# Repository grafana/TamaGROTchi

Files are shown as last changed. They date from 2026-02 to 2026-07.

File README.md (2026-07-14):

# Tamagrotchi

A Tamagotchi for Grafana users, featuring **Grot** as your virtual pet.
Keep Grot alive, watch him evolve, and observe his vital signs flowing into Grafana Cloud as OTLP metrics, logs, and traces.

Built for Grafana Labs Hackathon and featuring at the GrafanaCon Science Fair



---

## Building & Flashing

```bash
# Install PlatformIO CLI if needed
pip install platformio

# Build
pio run

# Flash firmware
pio run --target upload

# Flash filesystem (config.json)
pio run --target uploadfs

# Serial monitor
pio device monitor
```

---

## Configuration

Copy `data/config.json.example` to `data/config.json` and fill in your credentials:

```json
{
  "wifi": {
    "ssid": "YOUR_SSID",
    "password": "YOUR_PASSWORD"
  },
  "grafana": {
    "otlp_base": "https://otlp-gateway-prod-<region>.grafana.net/otlp",
    "auth_b64":  "Basic <your_grafana_cloud_token>",
    "device_id": "tamagrotchi"
  },
  "game": {
    "demo_speed": false,
    "push_interval_s": 60,
    "buzzer": true,
    "flash_alerts": true
  },
  "display": {
    "bgr_order": false
  }
}
```

If your display colours seem odd, then set bgr_order to true

> **Auth note:** `auth_b64` must be `Basic <base64(instanceId:glc_token)>` — Grafana Cloud OTLP uses standard Basic auth where the username is your stack's OTLP instance ID and the password is the `glc_` token. Find the instance ID on the **OpenTelemetry → Configure** page of your Grafana Cloud stack, then encode the pair with:
>
> ```sh
> echo -n "<instanceId>:<glc_token>" | base64
> ```
>
> Passing the raw `glc_` token after "Basic" will result in `401 Unauthorized`.

Upload the filesystem image after editing: **PlatformIO → Upload Filesystem Image**.

---

## Hardware

The physical device is built around a Waveshare ESP32-S3-Touch-LCD-1.69

| Component | Detail |
|---|---|
| MCU | ESP32-S3, dual-core 240 MHz, 8 MB PSRAM |
| Display | 240×280 ST7789V2 IPS, SPI @ 40 MHz |
| IMU | QMI8658C (accel + gyro) via I2C |
| RTC | PCF85063A via I2C |
| Touch | CST816 capacitive (I2C) |
| Buttons | A / B / C (GPIO3, 17, 18 — active-LOW) |
| Buzzer | GPIO42 via LEDC |
| Battery | LiPo with ADC divider on GPIO1 |

A printable case is included in `hardware/` (STL + 3MF).

Instructions are available at [hardware/hardware-bom.md](hardware/hardware-bom.md)

---

## The App

### Grot's Life Cycle
- 6 life stages: **Egg → Baby → Child → Teen → Adult → Senior**
- Evolution triggered by age thresholds, with an "EVOLVING…" overlay and melody
- **Evolution quality** (Excellent / Good / Tired) determined by accumulated care mistakes — affects which sprite set is shown

### Vitals
- **Hunger**, **Happiness**, **Health** — all 0–100
- Stats decay each game tick; health slowly recovers when both hunger and happiness are above 50
- Alerts fire (buzzer + log) when either falls below threshold
- Sustained low hunger causes sickness; untreated sickness causes death

### Player Actions
| Button | Action |
|---|---|
| A | Previous Menu |
| B | Select |
| C | Next Menu |
| B (when Idle) | Cycle through animations |
| Gentle shake | Play / wake from sleep |
| Hard shake | Dizzy (-5 happiness, status effect) |

### Sleep / Wake
- Grot sleeps from 22:00 to 08:00 (RTC-based)
- Waking him early is a care mistake
- NTP time is synced to the hardware RTC on first WiFi connection

### Sprites
All frames use `LV_COLOR_FORMAT_RGB565A8` (RGB565 + alpha map), rendered at 3× scale via LVGL image-level transforms.

| Sprite sheet | Size | Frames | Used for |
|---|---|---|---|
| `egg-shake.png` | 38×38 | 3 | Egg idle + periodic shake animation |
| `grot.png` | 32×32 | 4 | Baby idle, tired adult idle |
| `grot-blink.png` | 32×32 | 2 | Sleeping |
| `grot-wave.png` | 32×32 | 6 | Happy (baby, child, good adult) |
| `grot-walk.png` | 32×32 | 8 | Child idle, excellent adult idle (+ left-facing variant) |
| `grot-jumping.png` | 32×32 | 8 | Happy (excited adult), dizzy (last 4 fr) |
| `grot-thinks.png` | 32×32 | 5 | Sad, sick, dead |

The egg sits still for ~3 s then shakes (three 50 ms frames) before returning to rest.

### Telemetry → Grafana Cloud
All telemetry is sent via **OTLP/HTTP JSON** to Grafana Cloud on a configurable interval (default 60 s).

**Metrics** (`/v1/metrics`):
- `grot.hunger`, `grot.happiness`, `grot.health` — vital signs
- `grot.age_seconds` — pet age
- `grot.care_mistakes` — evolution quality indicator
- `grot.battery_voltage` — LiPo charge level
- `grot.wifi_rssi` — signal strength
- `grot.accel_mag` — IMU acceleration magnitude

**Logs** (`/v1/logs`): structured events including boot, hunger alerts, happiness alerts, feeding, playing, sickness, evolution, and death.

**Traces** (`/v1/traces`): spans for user actions (feed, play, medicine, discipline) and game events.

Each device generates a random `game_id` (e.g. `Lokirzu`, `Grotpup`) from ~2 025 combinations, used as `service.name` across all three signals so metrics, logs, and traces correlate automatically in Grafana.

The OTLP push runs on a background FreeRTOS task (Core 0) so the game loop is never blocked by network I/O. A small notification confirms each push.

---

## PC Simulator

`simulator/` is a Python multi-instance simulator that produces **format-identical OTLP telemetry** to the ESP32 firmware — useful for load-testing dashboards or generating a rich dataset without hardware.

```bash
cd simulator
pip install -r requirements.txt

python sim.py \
  --instances 20 \
  --otlp-base https://otlp-gateway-prod-us-east-0.grafana.net/otlp \
  --auth "Basic glc_..." \
  --speed 1.0 \
  --push-interval 30
```

Or create `simulator/config.json` (see `config.json.example`) and just run `python sim.py`.

We also have a helm chart to deploy a fleet of Grots to your k8s cluster

**Options:**

| Flag | Default | Description |
|---|---|---|
| `--instances N` | 5 | Number of simultaneous pets |
| `--otlp-base URL` | — | OTLP gateway base URL |
| `--auth TOKEN` | — | `Basic <base64(instanceId:glc_token)>` auth header |
| `--speed FLOAT` | 1.0 | Simulation speed multiplier |
| `--push-interval S` | 30 | OTLP push interval in seconds |
| `--verbose` | off | Print per-push HTTP status |
| `--no-traces` | off | Skip trace pushes |
| `--no-logs` | off | Skip log pushes |

Instance 0 is always named **Beylazu** — a fixed anchor for dashboards. All other instances get randomised `game_id` names.

---

---

## Adding / Updating Sprites

```bash
# Re-convert a sprite sheet (frames arranged horizontally, height = frame size)
python3 tools/png_to_lvgl.py src/sprites/grot-wave.png

# The script outputs one .cpp file per frame, e.g. grot_wave_0.cpp … grot_wave_5.cpp
# Wire new frames into src/sprites/grot_frames.cpp
```

The egg sprite (`egg-shake.png`) uses 38×38 px frames; all other sprites use 32×32 px.

---

## Tech Stack

| Layer | Library |
|---|---|
| Framework | Arduino (ESP-IDF 5.x underneath) |
| Build system | PlatformIO |
| Display driver | LovyanGFX 1.1.16 |
| UI toolkit | LVGL v9.3.0 |
| JSON | ArduinoJson 7.1.0 |
| IMU | FastIMU 1.2.6 |
| Filesystem | LittleFS |
| Telemetry | OTLP/HTTP JSON (custom, no SDK) |

---

## Contributing

Using Visual Studio Code, the easiest way is to install the PlatformIO extension. You can then rely on the PlatformIO config in the repo to build, monitor, and flash the hardware.

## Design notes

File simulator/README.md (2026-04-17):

# Tamagrotchi Simulator

A Python simulator that runs multiple Tamagotchi instances in parallel, using **game logic identical** to the ESP32-S3 firmware. Each virtual pet has its own game loop, random action scheduler, and OTLP telemetry push — output is format-identical to the hardware device for Grafana Cloud.

Use it to load-test dashboards, exercise OTLP pipelines, or develop against the same metrics/logs/traces without physical hardware.

---

## Requirements

- **Python 3.10+** (uses type hints and modern syntax)
- **requests** — see `requirements.txt`

```bash
pip install -r requirements.txt
```

---

## Quick start

1. **Copy the example config** and add your Grafana Cloud OTLP credentials:

   ```bash
   cp config.json.example config.json
   ```

   Edit `config.json`:

   - `otlp_base` — OTLP gateway URL (e.g. `https://otlp-gateway-prod-us-east-0.grafana.net/otlp`)
   - `auth` — Authorization header value (e.g. `Basic glc_eyJ...`). See [Getting the auth value](#getting-the-auth-value) below if you don’t have one yet.

2. **Run the simulator:**

   ```bash
   python sim.py
   ```

   This uses values from `config.json`. You can override any of them with CLI flags (see below).

### Getting the auth value

If you don’t have a Grafana Cloud API token yet:

1. **Sign in** to the [Grafana Cloud Portal](https://grafana.com/auth/sign-in/).
2. Open your **organization**, then select the **stack** you want to send data to (or create one).
3. Go to **Connections** (or **Add new connection**), then find the **OpenTelemetry** or **OTLP** tile and click **Configure** (or **Launch** then Configure).
4. On the OTLP configuration page you’ll see:
   - Your **OTLP endpoint URL** — use this for `otlp_base` (e.g. `https://otlp-gateway-prod-us-east-0.grafana.net/otlp`).
   - Instructions to **create an API token** and the **Authorization** header value.
5. **Create a token** if prompted (e.g. “Create token” or “Generate token”). Grafana Cloud often shows a value like `Basic glc_eyJ...` (a long base64-like string). That is the full header value.
6. **Copy the entire string** (including the word `Basic` and the space) into `config.json` as the `auth` value. No extra encoding is needed — paste it as shown.

If the UI gives you only a **raw token** (e.g. `glc_eyJ...` without `Basic `), set `auth` to exactly:

```text
Basic <paste-the-token-here>
```

So the value is the word `Basic`, a single space, then the token. Do not base64-encode the token yourself; Grafana Cloud tokens are already in the format they expect.

For more detail, see [Send data to the Grafana Cloud OTLP endpoint](https://grafana.com/docs/grafana-cloud/send-data/otlp/send-data-otlp/).

---

## Configuration

| Option | Config key | Default | Description |
|---|---|---|---|
| `--instances` | `instances` | 5 | Number of simultaneous virtual pets |
| `--otlp-base` | `otlp_base` | (required) | OTLP gateway base URL |
| `--auth` | `auth` | (required) | Auth header (e.g. `Basic glc_...`) |
| `--device-prefix` | `device_prefix` | `sim` | Device IDs become `sim-00`, `sim-01`, … |
| `--speed` | `speed` | 1.0 | Simulation speed (2.0 = 2× faster) |
| `--push-interval` | `push_interval` | 30 | Seconds between OTLP metric/log/trace pushes |
| `--verbose` | `verbose` | false | Print per-push HTTP status |
| `--no-traces` | — | — | Skip trace/span pushes (saves quota) |
| `--no-logs` | — | — | Skip log pushes (saves quota) |
| `--status-interval` | — | 30 | Seconds between status table prints |

**Config file:** `simulator/config.json`. CLI flags override config values.

**Example with CLI only:**

```bash
python sim.py --instances 20 \
  --otlp-base https://otlp-gateway-prod-us-east-0.grafana.net/otlp \
  --auth "Basic glc_eyJ..." \
  --device-prefix sim \
  --speed 1.0 \
  --push-interval 30
```

---

## What it does

- **One thread per pet.** Each instance has its own `PetState`, game tick loop, and OTLP client.
- **Game tick every 1 second** (scaled by `--speed`): stat decay, alerts, sickness, evolution, death — same constants and logic as `game_engine.cpp` / `evolution.cpp` / `actions.cpp`.
- **Random actions:** feed, play, medicine, discipline, and occasional shake are scheduled with exponential jitter so pets get varied care (and sometimes care mistakes).
- **OTLP push** on the given interval: metrics (`grot.hunger`, `grot.happiness`, etc.), buffered logs, and traces in the same format as the firmware.
- **Status table** printed to stdout every `--status-interval` seconds: device, stage, vitals, age, care mistakes, last event.

When a pet dies (health depleted or old age), its thread exits after a short delay; the others keep running. Use **Ctrl-C** to stop all instances gracefully (they flush before exit).

---

## Layout

| File | Role |
|---|---|
| `sim.py` | Entry point: CLI/config, spawns one thread per instance, status table loop |
| `game_logic.py` | Game tick, evolution, and actions — mirrors firmware `config.h` + game engine |
| `pet_state.py` | `PetState` dataclass and enums (`LifeStage`, `PetStatus`, `EvoQuality`) — mirrors `pet_state.h` |
| `otlp_client.py` | OTLP/HTTP JSON client: metrics, logs, traces — format-identical to `otlp_writer.cpp` |
| `config.json` | Local config (not committed; copy from `config.json.example`) |
| `config.json.example` | Example config with placeholder auth |
| `requirements.txt` | Python deps (`requests`) |

---

## Game behavior (same as firmware)

- **Life stages:** Egg → Baby → Child → Teen → Adult → Senior → Dead (age thresholds in `game_logic.py`).
- **Evolution quality:** Excellent / Good / Tired from care mistakes at evolution time.
- **Vitals:** Hunger, happiness, health 0–100; decay per tick; alerts when hunger or happiness is low; sustained low hunger → sickness → health drain → death.
- **Actions:** Feed (microchip / sin_wave), play, medicine, discipline, shake (gentle → play, hard → dizzy).
- **Sleep:** Simulator does not enforce RTC sleep; `is_sleeping` can be used for future extensions.

Numeric constants (decay rates, thresholds, evolution ages, etc.) are taken from the firmware so dashboards and alerts behave the same as on device.

---

## Telemetry

- **Metrics** (e.g. `grot.hunger`, `grot.happiness`, `grot.health`, `grot.age_seconds`, `grot.care_mistakes`, `grot.battery_voltage` sim, `grot.wifi_rssi`, `grot.accel_mag`) — same names and semantics as firmware; battery is simulated or fixed for sim.
- **Logs** — event + body (e.g. `boot`, `fed`, `evolved`, `sick`, `death`, `alert_missed`).
- **Traces** — spans for user actions and game events (e.g. `user.feed`, `pet.fed`, `pet.evolved`, `pet.died`).

Use `--no-traces` or `--no-logs` to reduce quota usage while still testing metrics.

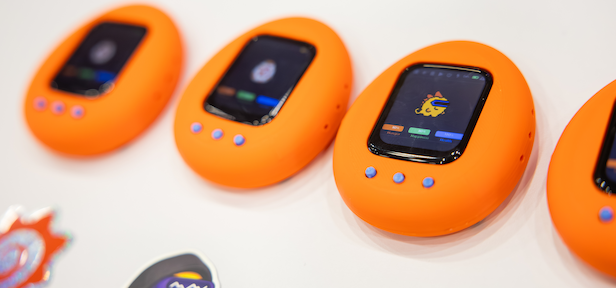
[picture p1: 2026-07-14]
hardware/tamagrotchis-chilling.png

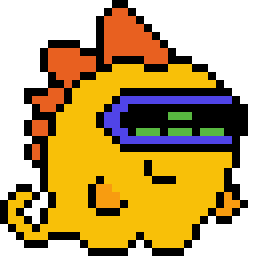
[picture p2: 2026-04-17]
src/sprites/grot_thinks_2_8x.png

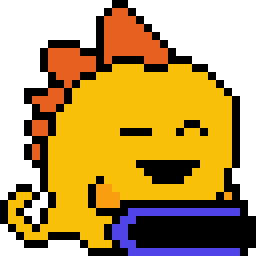
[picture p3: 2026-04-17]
src/sprites/grot_blink_1_8x.png

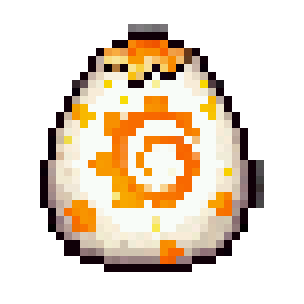
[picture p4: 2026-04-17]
src/sprites/egg_shake_0_8x.png

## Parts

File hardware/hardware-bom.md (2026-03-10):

# Tamagrotchi — Bill of Materials & Build Guide

---

## Bill of Materials

| # | Item | Notes | Qty |
|---|---|---|-----|
| 1 | **Waveshare ESP32-S3-Touch-LCD-1.69** | Main board — includes ST7789V2 display, QMI8658C IMU, PCF85063A RTC, CST816D touch, USB-C charging. Search: `ESP32-S3-Touch-LCD-1.69` | 1 |
| 2 | **LiPo battery** | 3.7 V, 402030 size (4×20×30 mm) fits the case. Any single-cell LiPo with JST-SH 1.25 mm 2-pin connector. ~200–400 mAh recommended. | 1 |
| 3 | **Tactile push buttons** | 6×6 mm or 6×6×5 mm THT momentary switches (3 required: A / B / C). Standard 4-pin PCB type. | 3 |
| 6 | **Jumper wires / ribbon cable** | 2–3 cm, for connecting buttons to the board header. | 4 |
| 7 | **Small perfboard or breadboard** | For mounting the three buttons cleanly | 1 |
| 8 | **M3×8 mm screws** | For closing the case halves. | 4 |
| 9 | **M3 heatset inserts** | Press in to front of case | 4 |
| 10 | **3D-printed case** | Print `hardware/tamagrotchi-face.stl` + `hardware/tamagrotchi-back.stl`. See printing notes below. `button.stl` provides keycaps. | 1 set |
| 11 | **2mm double sided electronic tape** | To afix screen to case and keep printed buttons attached to the tactile buttons | 10cm |

### Optional / Nice to Have

| Item | Purpose |
|---|---|
| Kapton tape | Insulate battery against board back |
| Thin double-sided tape | Secure battery inside case |
| Hot glue | Anchor buttons if they shift |
| JST-SH 1.25 mm 2-pin male plug | If your battery connector doesn't match the board |

---

## GPIO Wiring

The Waveshare board exposes a GPIO header. Wire the external components as follows:

| Signal | GPIO | External Component | Notes |
|---|---|---|---|
| Button A | GPIO 3 | Tactile switch → GND | INPUT_PULLUP, active-LOW |
| Button B | GPIO 17 | Tactile switch → GND | INPUT_PULLUP, active-LOW |
| Button C | GPIO 18 | Tactile switch → GND | INPUT_PULLUP, active-LOW |
| Battery | JST-SH on board | LiPo + / − | Board has onboard charging IC |

All on-board peripherals (display, IMU, RTC, touch, buzzer) are already wired internally — no extra connections needed.

---

## 3D Printing

Files are in `hardware/`:

| File | Part |
|---|---|
| `tamagrotchi-face.stl` | Front shell (display window + button holes) |
| `tamagrotchi-back.stl` | Back shell (battery compartment) |
| `button.stl` | Optional button keycaps |
| `tamagrotchi.3mf` | Combined project file (Bambu/PrusaSlicer) |
| `tamagrotchi.f3z` | Fusion project file with all case designs |

### Print Settings

I printed the original case using a Bambu X1 carbon but they aren't difficult prints. 
I would love to see a resin version!

| Setting | Recommended |
|---|---|
| Material | PLA or PETG |
| Layer height | 0.15–0.2 mm |
| Infill | 20% |
| Adaptive layer height | if available! |
| Supports | yes |
| Orientation | Flat for the front shell; reverse down for the back |

---

## Assembly Steps

### 1 — Print the case
Print both shells. Clean up any stringing around the button holes and display window.

### 2 - Place heat set inserts
Use a soldering iron to push the heatset inserts in to the rear of the front case half

### 3 — Flash firmware first
Before assembling, flash the firmware and filesystem image with the board connected via USB-C, and verify the display and OTLP telemetry work:
```bash
pio run --target upload
pio run --target uploadfs
pio device monitor
```

### 4 — Prepare the buttons
Solder three tactile switches to a small piece of perfboard. Run a common GND wire and individual signal wires for GPIO 3, 17, 18.

### 5 - Apply tape to edges of screen
Use the double sided 2mm electronic tape and apply it to the rear of the screen.

### 6 — Seat the board in the front shell
The display is pushed in from the front of the case. The board sits against the front shell with the USB-C port accessible from the edge.
Feed the button board through the front window and then push the screen in to place 

### 7 — Fit the battery
Place the LiPo in the back shell. Stick a layer of Kapton tape over the face of the battery that will rest against the board. Connect the JST-SH plug to the board.
PLEASE check the polarity. This is not a standard connector

### 8 — Close and screw
Bring the two shells together, thread M3 screws through the back into the front shell posts.

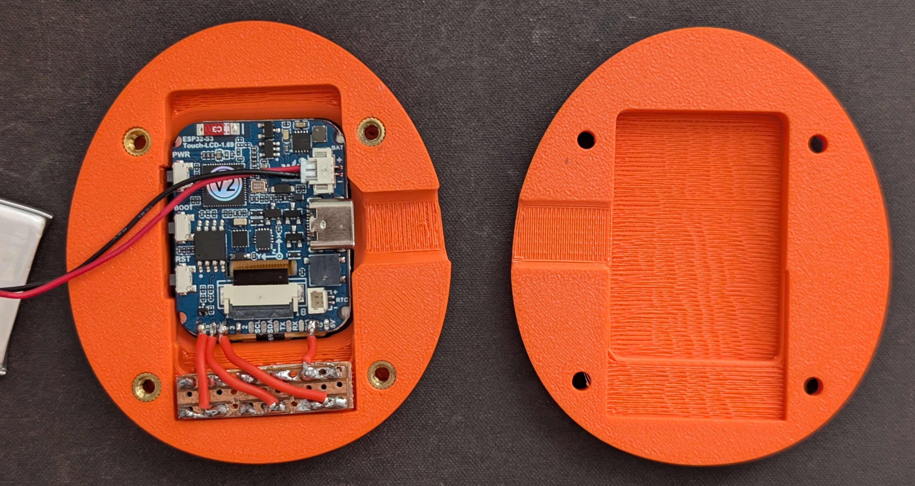
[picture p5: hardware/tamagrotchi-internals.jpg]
Tamagrotchi internals


---

## Power Notes

- The board's onboard charging IC charges the LiPo via USB-C. No separate charger needed.
- `PIN_SYS_EN` (GPIO 41) must be driven HIGH in firmware to keep the board on after the USB cable is removed — this is handled automatically in `main.cpp`.
- Battery percentage is read from a hardware 200 kΩ / 100 kΩ voltage divider on GPIO 1 (`BAT_DIVIDER_RATIO = 3.0`). The reported range maps 3.0 V → 0 %, 4.2 V → 100 %.
- **Note that the polarity on the board and batteries is not standardised. I had to depin and repin the battery connector before attaching**
---

## Total Cost Estimate

| Item | Approx. cost |
|---|---|
| Waveshare ESP32-S3-Touch-LCD-1.69 | ~$20–25 USD |
| LiPo battery (402030) | ~$3–5 USD |
| Buttons, buzzer, resistor, wires | ~$2–3 USD |
| 3D print filament | ~$0.50 USD |
| **Total** | **~$25–35 USD** |

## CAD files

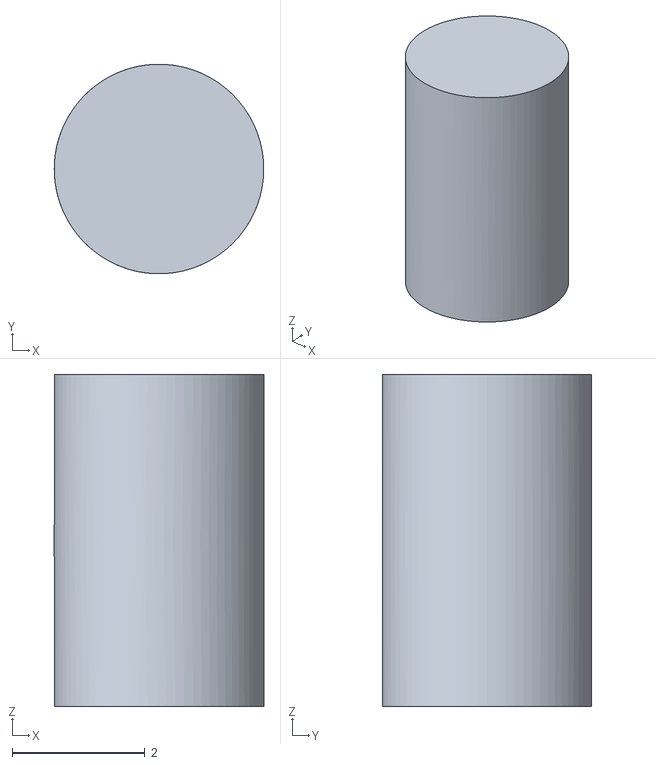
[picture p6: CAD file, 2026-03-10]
hardware/button.stl
3.16 x 3.15 x 5.00

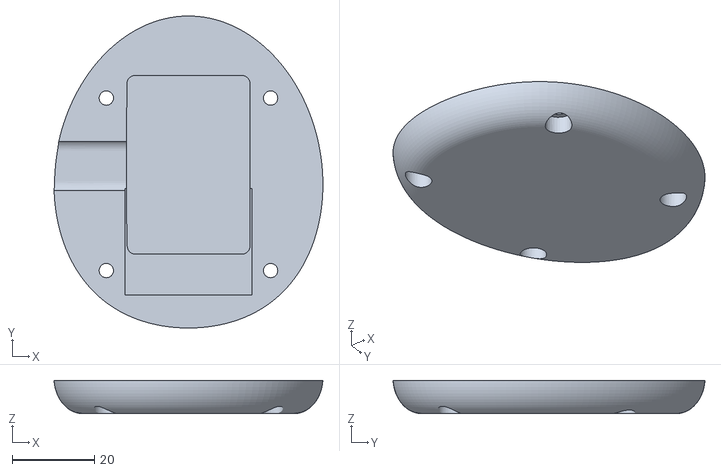
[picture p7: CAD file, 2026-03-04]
hardware/tamagrotchi-back.stl
65.5 x 76.0 x 8.10

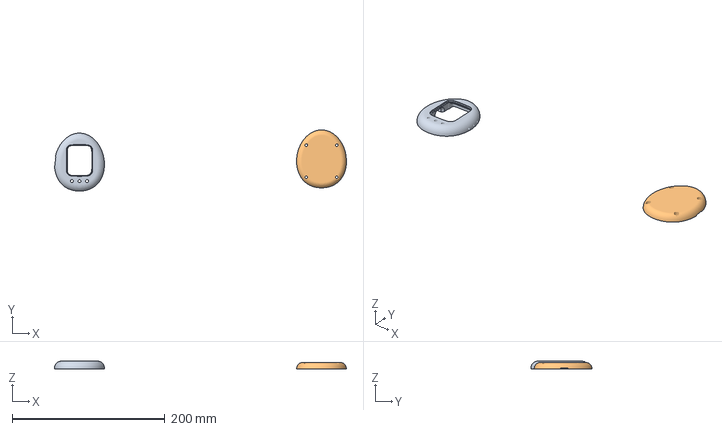
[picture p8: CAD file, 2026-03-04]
hardware/tamagrotchi.3mf
382.7 x 80.2 x 10.1 mm
tamagrotchi-face.stl
tamagrotchi-back.stl

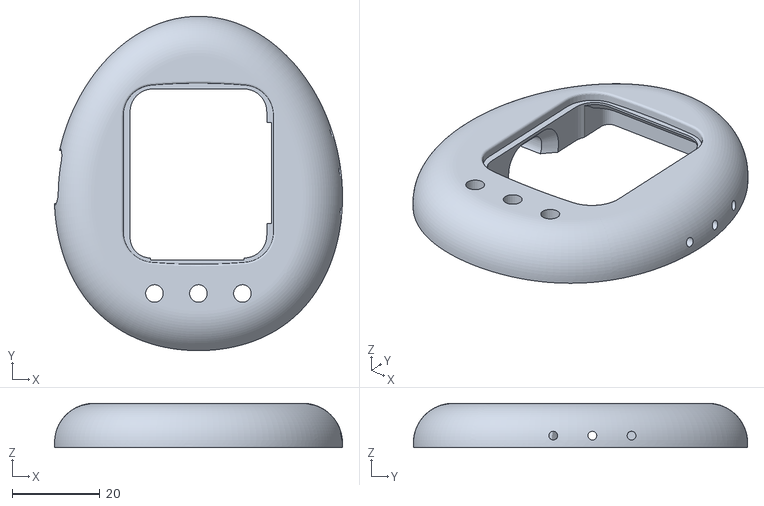
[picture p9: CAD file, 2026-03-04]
hardware/tamagrotchi-face.stl
65.5 x 76.0 x 10.1

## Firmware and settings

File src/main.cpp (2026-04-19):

// =============================================================================
// Tamagrotchi — Entry point
// Waveshare ESP32-S3-Touch-LCD-1.69 (ST7789V2, QMI8658C, PCF85063A)
// =============================================================================
#include <Arduino.h>
#include <WiFi.h>
#include <time.h>

#include "config.h"
#include "config_mgr/config_manager.h"
#include "display/lvgl_port.h"
#include "display/ui_screens.h"
#include "input/buttons.h"
#include "buzzer/buzzer.h"
#include "game/pet_state.h"
#include "game/game_engine.h"
#include "game/evolution.h"
#include "game/actions.h"
#include "game/mini_game_metric_catcher.h"
#include "sprites/sprite_engine.h"
#include "sprites/grot_frames.h"
#include "wifi/wifi_manager.h"
#include "telemetry/otlp_writer.h"
#include "imu/imu_driver.h"
#include "rtc/rtc_driver.h"
#include "power/battery.h"

// =============================================================================
// Globals
// =============================================================================
static PetState  g_pet;
static AppConfig g_cfg;
static uint8_t   _battery_pct = 100;   // refreshed on telemetry sample tick (16 ADC reads)

// =============================================================================
// UI state machine
// =============================================================================
enum class UiMode : uint8_t {
    IDLE,        // pet visible, no icon selected
    NAVIGATING,  // icon bar active, A/C scroll, B select
    SUB_STATUS,  // stats overlay, auto-close 4s or B
    SUB_FEED,    // food choice overlay, A/C toggle, B execute
    SUB_LIGHTS,  // lights confirm overlay, B=toggle A=cancel
    SUB_DISMISS, // generic text overlay, any key or 2s auto-dismiss
    MINI_GAME,   // metric catcher mini-game running
};

static UiMode   g_ui_mode      = UiMode::IDLE;
static MenuItem g_menu_item    = MenuItem::STATUS;
static int      g_feed_choice  = 0;           // 0=Microchip, 1=SIN-wave
static uint32_t g_sub_enter_ms = 0;
static bool     g_sprite_test  = false;       // true while B-cycle test is active

// =============================================================================
// game_log() / game_trace() — strong overrides for the __attribute__((weak))
// stubs in game_engine.cpp.  Routes telemetry to Serial + OTLP buffers.
// =============================================================================
void game_log(uint8_t level, const char* event, const char* msg) {
    Serial.printf("[%s] %s\n", event, msg);
    otlp_log(level, event, msg);
}

void game_trace(const char* name, const char* body, uint32_t dur_ms) {
    otlp_trace(name, body, dur_ms);
}

// =============================================================================
// setup()
// =============================================================================
void setup() {
    // 0. CPU frequency — 80 MHz is sufficient for a 1 Hz game loop.
    //    APB clock stays at 80 MHz at this setting so SPI/I2C are unaffected.
    setCpuFrequencyMhz(80);

    // 0b. Power latch — GPIO41 HIGH keeps the board on; GPIO40 is a sense input
    pinMode(PIN_SYS_EN,  OUTPUT);
    digitalWrite(PIN_SYS_EN,  HIGH);
    pinMode(PIN_SYS_OUT, INPUT);   // power sense — do NOT drive this pin

    Serial.begin(115200);
    // ESP32-S3 USB CDC needs time to re-enumerate after the boot reset.
    // Wait up to 2 s for the host to connect; fall through anyway so the
    // device doesn't hang when no PC is attached.
    { uint32_t t = millis(); while (!Serial && (millis() - t) < 2000) delay(10); }
    delay(100);
    Serial.println("\n[main] === Tamagrotchi boot ===");

    // 1. Load runtime config from LittleFS /config.json ----------------------
    config_manager_load(&g_cfg);
    config_manager_print(&g_cfg);

    // 2. Display + LVGL -------------------------------------------------------
    lvgl_port_init(g_cfg.bgr_order);   // init LovyanGFX + LVGL
    ui_screens_init();         // build all LVGL screens (also inits sprite engine)
    ui_show_game();            // activate main game screen

    // 3. Input ----------------------------------------------------------------
    buttons_init();

    // 4. Audio ----------------------------------------------------------------
    buzzer_init();
    buzzer_set_muted(!g_cfg.buzzer_enabled);
    if (g_cfg.flash_alerts)
        buzzer_set_play_cb([]() { display_alert_flash(2); });
    buzzer_play_async(MELODY_BOOT, MELODY_BOOT_LEN);

    // 5. IMU + RTC (Wire.begin called inside imu_driver_init) -----------------
    imu_driver_init();
    rtc_driver_init();
    battery_init();
    _battery_pct = battery_get_percent();   // prime the header indicator

    // 6. Pet state + game engine ----------------------------------------------
    pet_state_init(&g_pet);
    game_engine_init(&g_pet);

    // 7. WiFi (non-blocking) + telemetry writer -------------------------------
    wifi_manager_init(g_cfg.wifi_ssid, g_cfg.wifi_password);
    otlp_writer_init(g_cfg.otlp_base, g_cfg.auth_b64, g_cfg.device_id);
    otlp_writer_start_task();   // background push task on Core 0

    // 8. Boot log (buffered; flushed on first successful WiFi push) -----------
    char boot_msg[80];
    snprintf(boot_msg, sizeof(boot_msg),
             "stage=%s | firmware=1.0.0", life_stage_name(g_pet.stage));
    game_log(9 /*INFO*/, "boot", boot_msg);

    Serial.println("[main] Setup complete\n");
}

// =============================================================================
// loop()
// =============================================================================
enum class TelemetryPhase : uint8_t { WAKING, PUSHING, SLEEPING, ASLEEP };
static TelemetryPhase _telem_phase   = TelemetryPhase::WAKING;  // start connected for NTP
static uint32_t _last_push_ms        = 0;
static uint32_t _last_sample_ms      = 0;
static uint32_t _wake_start_ms       = 0;
static bool     _rtc_synced          = false;   // NTP → RTC written once
static bool     _dead_shown          = false;   // death screen shown once
static bool     _was_sleeping        = false;   // tracks last pet sleep state for backlight

void loop() {
    uint32_t now = millis();

    // 1. LVGL heartbeat -------------------------------------------------------
    lvgl_port_tick();

    // 2. Advance async buzzer melody ------------------------------------------
    buzzer_update();

    // 3. Debounce buttons, fill event ring buffer ------------------------------
    buttons_update();

    // 4. IMU read ~10 Hz -------------------------------------------------------
    static uint32_t _imu_ms = 0;
    if (now - _imu_ms >= 100) {
        _imu_ms = now;
        imu_driver_update();
    }

    // 5. Non-blocking WiFi FSM ------------------------------------------------
    wifi_manager_update();

    // 6. Sync NTP time back to hardware RTC (once, after SNTP settles) --------
    if (!_rtc_synced) {
        time_t t = time(nullptr);
        if (t > 1000000000L) {
            rtc_driver_sync_from_ntp(t);
            _rtc_synced = true;
        }
    }

    // 7. Game tick (internally rate-limited to GAME_TICK_MS) ------------------
    game_engine_update(&g_pet);

    // 8. UI state machine — icon menu navigation + action dispatch -------------
    {
        ButtonEvent evt = buttons_get_event();

        // Stop the mini-game immediately if the pet dies mid-game
        if (pet_is_dead(&g_pet) && g_ui_mode == UiMode::MINI_GAME) {
            metric_catcher_stop();
            g_ui_mode = UiMode::IDLE;
            ui_menu_set_selected(MenuItem::MENU_COUNT);
            ui_set_hints("", "", "");
        }

        // Dead screen: B press restarts the pet
        if (pet_is_dead(&g_pet)) {
            if (evt == ButtonEvent::B_PRESS) {
                pet_state_init(&g_pet);
                game_engine_init(&g_pet);
                _dead_shown = false;
                ui_show_game();
                ui_hide_overlay();
                g_ui_mode = UiMode::IDLE;
                ui_menu_set_selected(MenuItem::MENU_COUNT);
                ui_set_hints("", "", "");
            }
        } else {
            switch (g_ui_mode) {

            // ------------------------------------------------------------------
            case UiMode::IDLE:
                // A or C wakes the icon bar; exit sprite test mode
                if (evt == ButtonEvent::A_PRESS || evt == ButtonEvent::C_PRESS) {
                    g_sprite_test = false;
                    g_ui_mode = UiMode::NAVIGATING;
                    ui_menu_set_selected(g_menu_item);
                    ui_set_hints("[A] Prev", "[B] Select", "[C] Next");
                }
                // B cycles through sprite animation states (dev testing)
                if (evt == ButtonEvent::B_PRESS) {
                    g_sprite_test = true;
                    sprite_engine_test_next();
                }
                break;

            // ------------------------------------------------------------------
            case UiMode::NAVIGATING: {
                const int n = (int)MenuItem::MENU_COUNT;
                if (evt == ButtonEvent::A_PRESS) {
                    g_menu_item = (MenuItem)(((int)g_menu_item - 1 + n) % n);
                    ui_menu_set_selected(g_menu_item);
                } else if (evt == ButtonEvent::C_PRESS) {
                    g_menu_item = (MenuItem)(((int)g_menu_item + 1) % n);
                    ui_menu_set_selected(g_menu_item);
                } else if (evt == ButtonEvent::B_PRESS) {
                    // Activate selected icon
                    switch (g_menu_item) {
                    case MenuItem::STATUS:
                        g_ui_mode      = UiMode::SUB_STATUS;
                        g_sub_enter_ms = now;
                        ui_show_overlay_status(&g_pet, battery_read_voltage(),
                                               otlp_get_game_id());
                        ui_set_hints("", "[B] Close", "");
                        break;
                    case MenuItem::FEED:
                        g_ui_mode     = UiMode::SUB_FEED;
                        g_feed_choice = 0;
                        ui_show_overlay_feed(g_feed_choice);
                        ui_set_hints("[A] Prev", "[B] Feed!", "[C] Next");
                        break;
                    case MenuItem::CLEAN:
                        if (g_pet.hasP1) {
                            otlp_trace_begin("user.clean", "action=clean", 600);
                            action_clean(&g_pet);
                            otlp_trace_end();
                            g_ui_mode      = UiMode::SUB_DISMISS;
                            g_sub_enter_ms = now;
                            ui_show_overlay_text("P1 Resolved!\n\nHealth +10");
                        } else {
                            g_ui_mode      = UiMode::SUB_DISMISS;
                            g_sub_enter_ms = now;
                            ui_show_overlay_text("Nothing to clean\n\nData stream is clear");
                        }
                        ui_set_hints("", "[B] OK", "");
                        break;
                    case MenuItem::GAME:
                        metric_catcher_start(&g_pet);
                        g_ui_mode = UiMode::MINI_GAME;
                        ui_menu_set_selected(MenuItem::MENU_COUNT);
                        ui_set_hints("[A] Left", "[B] Quit", "[C] Right");
                        break;
                    case MenuItem::LIGHTS:
                        g_ui_mode      = UiMode::SUB_LIGHTS;
                        g_sub_enter_ms = now;
                        ui_show_overlay_text(g_pet.isSleeping
                            ? "Wake Grot up?\n\n[B] Wake  [A] Cancel"
                            : "Put Grot to sleep?\n\n[B] Sleep  [A] Cancel");
                        ui_set_hints("[A] Cancel", "[B] Confirm", "");
                        break;
                    case MenuItem::MEDICINE: {
                        bool was_sick = (g_pet.status == PetStatus::SICK);
                        otlp_trace_begin("user.medicine", "action=medicine", 600);
                        action_medicine(&g_pet);
                        otlp_trace_end();
                        g_ui_mode      = UiMode::SUB_DISMISS;
                        g_sub_enter_ms = now;
                        ui_show_overlay_text(was_sick
                            ? "Medicine given!\nHealth restored"
                            : "Medicine given");
                        ui_set_hints("", "[B] OK", "");
                        break;
                    }
                    default: break;
                    }
                } else if (evt == ButtonEvent::B_LONG) {
                    // Long-press B cancels navigation
                    g_ui_mode = UiMode::IDLE;
                    ui_menu_set_selected(MenuItem::MENU_COUNT);
                    ui_hide_overlay();
                    ui_set_hints("", "", "");
                }
                break;
            }

            // ------------------------------------------------------------------
            case UiMode::SUB_STATUS:
                // Auto-close after 4s or on B press
                if (evt == ButtonEvent::B_PRESS ||
                    (now - g_sub_enter_ms) >= 4000UL) {
                    ui_hide_overlay();
                    g_ui_mode = UiMode::IDLE;
                    ui_menu_set_selected(MenuItem::MENU_COUNT);
                    ui_set_hints("", "", "");
                }
                break;

            // ------------------------------------------------------------------
            case UiMode::SUB_FEED:
                if (evt == ButtonEvent::A_PRESS || evt == ButtonEvent::C_PRESS) {
                    g_feed_choice ^= 1;  // toggle 0↔1
                    ui_show_overlay_feed(g_feed_choice);
                } else if (evt == ButtonEvent::B_PRESS) {
                    FoodType food = (g_feed_choice == 0)
                                  ? FoodType::MICROCHIP
                                  : FoodType::SIN_WAVE;
                    otlp_trace_begin("user.feed",
                        g_feed_choice == 0 ? "food=microchip" : "food=sin_wave", 600);
                    action_feed(&g_pet, food);
                    otlp_trace_end();
                    ui_hide_overlay();
                    g_ui_mode = UiMode::IDLE;
                    ui_menu_set_selected(MenuItem::MENU_COUNT);
                    ui_set_hints("", "", "");
                } else if (evt == ButtonEvent::B_LONG) {
                    ui_hide_overlay();
                    g_ui_mode = UiMode::IDLE;
                    ui_menu_set_selected(MenuItem::MENU_COUNT);
                    ui_set_hints("", "", "");
                }
                break;

            // ------------------------------------------------------------------
            case UiMode::SUB_LIGHTS:
                if (evt == ButtonEvent::B_PRESS) {
                    if (g_pet.isSleeping) {
                        action_wake(&g_pet, rtc_get_hour());
                    } else {
                        g_pet.isSleeping = true;
                        g_pet.status     = PetStatus::SLEEPING;
                        game_log(9, "sleeping", "manual sleep via lights menu");
                    }
                    ui_hide_overlay();
                    g_ui_mode = UiMode::IDLE;
                    ui_menu_set_selected(MenuItem::MENU_COUNT);
                    ui_set_hints("", "", "");
                } else if (evt == ButtonEvent::A_PRESS || evt == ButtonEvent::B_LONG) {
                    ui_hide_overlay();
                    g_ui_mode = UiMode::IDLE;
                    ui_menu_set_selected(MenuItem::MENU_COUNT);
                    ui_set_hints("", "", "");
                }
                break;

            // ------------------------------------------------------------------
            case UiMode::SUB_DISMISS:
                // Any button press or 2s auto-dismiss
                if (evt != ButtonEvent::NONE ||
                    (now - g_sub_enter_ms) >= 2000UL) {
                    ui_hide_overlay();
                    g_ui_mode = UiMode::IDLE;
                    ui_menu_set_selected(MenuItem::MENU_COUNT);
                    ui_set_hints("", "", "");
                }
                break;

            // ------------------------------------------------------------------
            case UiMode::MINI_GAME:
                metric_catcher_handle_input(evt);
                if (!metric_catcher_is_running()) {
                    g_ui_mode = UiMode::IDLE;
                    ui_menu_set_selected(MenuItem::MENU_COUNT);
                    ui_set_hints("", "", "");
                }
                break;
            }
        }
    }

    // 9. Shake interactions ---------------------------------------------------
    ShakeLevel shake = imu_get_shake();
    if (shake != ShakeLevel::NONE && !pet_is_dead(&g_pet)) {
        float mag = imu_get_accel_mag();

        if (shake == ShakeLevel::HARD) {
            // Hard shake → dizzy, lose 5 happiness
            char shake_body[48];
            snprintf(shake_body, sizeof(shake_body), "level=hard | accel_mag=%.2f", (double)mag);
            otlp_trace_begin("sensor.shake", shake_body, 2000);
            action_dizzy(&g_pet, mag);
            otlp_trace_end();
        } else {
            // Gentle shake
            if (g_pet.isSleeping) {
                // Wake early → care mistake if before wakeHour
                action_wake(&g_pet, rtc_get_hour());
            } else {
                char msg[48];
                snprintf(msg, sizeof(msg),
                         "accel_mag=%.2f | action=play", (double)mag);
                game_log(9, "shake_play", msg);
                char shake_body[48];
                snprintf(shake_body, sizeof(shake_body), "level=gentle | accel_mag=%.2f", (double)mag);
                otlp_trace_begin("sensor.shake", shake_body, 1000);
                game_trace("pet.shake_play", msg, 0);
                action_play(&g_pet);
                otlp_trace_end();
            }
        }
    }

    // 10. Evolution overlay ---------------------------------------------------
    if (g_pet.evolveReady &&
        g_pet.status != PetStatus::EVOLVING &&
        g_pet.status != PetStatus::DEAD) {
        g_pet.status        = PetStatus::EVOLVING;
        g_pet.statusStartMs = now;
        ui_show_evolve_overlay(true);
        buzzer_play_async(MELODY_EVOLVE, MELODY_EVOLVE_LEN);
    }
    // Complete the transition after the 3-second animation
    if (g_pet.status == PetStatus::EVOLVING &&
        (now - g_pet.statusStartMs) >= 3000UL) {
        ui_show_evolve_overlay(false);
        char evo_body[32];
        snprintf(evo_body, sizeof(evo_body), "from=%s", life_stage_name(g_pet.stage));
        otlp_trace_begin("lifecycle.evolve", evo_body, 3000);
        evolution_advance(&g_pet);   // advances stage, computes quality, clears evolveReady
        otlp_trace_end();
    }

    // 11. Death screen (shown once) -------------------------------------------
    if (pet_is_dead(&g_pet) && !_dead_shown) {
        _dead_shown = true;
        ui_show_dead();
        buzzer_play_async(MELODY_DEAD, MELODY_DEAD_LEN);
    }

    // 12. Refresh UI ----------------------------------------------------------
    ui_update_vitals(&g_pet);
    ui_update_header(&g_pet, wifi_manager_is_connected(), _battery_pct);
    // Skip sprite state update while the B-cycle dev test is active or the
    // mini-game is running (both manage the sprite state themselves).
    if (!g_sprite_test && g_ui_mode != UiMode::MINI_GAME) {
        sprite_engine_set_state(g_pet.stage,
                                game_engine_get_emotion(&g_pet),
                                g_pet.quality);
    }

    // 12b. Sleep-aware backlight — dim when pet sleeps, restore on wake ------
    if (g_pet.isSleeping != _was_sleeping) {
        _was_sleeping = g_pet.isSleeping;
        lvgl_port_set_brightness(g_pet.isSleeping ? LCD_BL_SLEEP : LCD_BL_NORMAL);
    }

    // 13. Telemetry: sample metrics into buffer every sample_interval_s -------
    uint32_t sample_interval_ms = g_cfg.sample_interval_s * 1000UL;
    if ((now - _last_sample_ms) >= sample_interval_ms) {
        _last_sample_ms = now;
        // Share a single ADC read between telemetry and the header indicator
        float batt_v = battery_read_voltage();
        _battery_pct = battery_v_to_percent(batt_v);
        otlp_sample_metrics(&g_pet, imu_get_accel_mag(), batt_v);
    }

    // 13b. WiFi sleep/wake FSM — batch push once per push_interval_s ---------
    uint32_t push_interval_ms = g_cfg.push_interval_s * 1000UL;

    switch (_telem_phase) {

    case TelemetryPhase::ASLEEP:
        if ((now - _last_push_ms) >= push_interval_ms) {
            _wake_start_ms = now;
            wifi_manager_wake();
            _telem_phase = TelemetryPhase::WAKING;
        }
        break;

    case TelemetryPhase::WAKING:
        if (wifi_manager_is_connected()) {
            otlp_schedule_push(&g_pet, imu_get_accel_mag(), WiFi.RSSI(),
                               battery_read_voltage());
            _telem_phase = TelemetryPhase::PUSHING;
        } else if ((now - _wake_start_ms) >= WIFI_WAKE_TIMEOUT_MS) {
            // Failed to connect — skip push, sleep, retry next window
            wifi_manager_sleep();
            _last_push_ms = now;
            _telem_phase  = TelemetryPhase::ASLEEP;
            game_log(13, "wifi_wake_timeout", "skipping push");
        }
        break;

    case TelemetryPhase::PUSHING:
        if (otlp_push_complete()) {
            ui_show_push_toast(otlp_last_push_ok());
            _last_push_ms = now;
            wifi_manager_sleep();
            _telem_phase = TelemetryPhase::SLEEPING;
        }
        break;
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

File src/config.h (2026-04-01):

#pragma once

// =============================================================================
// Tamagrotchi — Central Hardware & Tuning Constants
// =============================================================================

// --- Display SPI (Waveshare ESP32-S3-Touch-LCD-1.69) -------------------------
#define PIN_LCD_SCLK        6
#define PIN_LCD_MOSI        7
#define PIN_LCD_CS          5
#define PIN_LCD_DC          4
#define PIN_LCD_RST         8
#define PIN_LCD_BL          15
#define LCD_WIDTH           240
#define LCD_HEIGHT          280
#define LCD_SPI_FREQ        80000000UL  // 80 MHz write
#define LCD_SPI_FREQ_READ   16000000UL

// --- I2C (shared: CST816D touch, QMI8658C IMU, PCF85063 RTC) ----------------
#define PIN_I2C_SDA         11
#define PIN_I2C_SCL         10
#define I2C_FREQ            400000

#define TOUCH_I2C_ADDR      0x15  // CST816D (not used for input)
#define IMU_I2C_ADDR        0x6B  // QMI8658C
#define RTC_I2C_ADDR        0x51  // PCF85063A

// --- Buttons (GPIOs broken out on board header) ------------------------------
#define PIN_BTN_A           3   // Left  / Feed      — header pin GPIO3
#define PIN_BTN_B           17  // Select / Menu     — header pin GPIO17
#define PIN_BTN_C           18  // Right / Play      — header pin GPIO18
#define BTN_DEBOUNCE_MS     30
#define BTN_LONG_PRESS_MS   800

// --- Buzzer ------------------------------------------------------------------
#define PIN_BUZZER          42
#define BUZZER_LEDC_CH      0   // LEDC channel 0 (channel 1 reserved for backlight)
#define BUZZER_LEDC_RES     10  // 10-bit resolution
// Note: passive piezo volume is hardware-only (series resistor on GPIO42).
// Software duty != 512 creates harsh harmonics. Keep at 512 for clean tone.
#define BUZZER_DUTY         512

// --- Battery ADC -------------------------------------------------------------
#define PIN_BAT_ADC         1   // GPIO1 — battery voltage via 200kΩ/100kΩ divider
#define BAT_DIVIDER_RATIO   3.0f  // (R1+R2)/R2 = (200k+100k)/100k
#define BAT_V_FULL          4.2f  // LiPo fully charged
#define BAT_V_EMPTY         3.0f  // LiPo cutoff voltage
#define BAT_ADC_SAMPLES     16    // Readings averaged per measurement

// --- Power -------------------------------------------------------------------
#define PIN_SYS_EN          41  // Hold HIGH to keep power on
#define PIN_SYS_OUT         40  // Power output control

// --- LVGL draw buffer --------------------------------------------------------
#define LV_BUF_LINES        40  // Lines per draw buffer (240×40×2 = 19.2KB each)

// --- Backlight brightness (0-255) -------------------------------------------
// Reducing from 255 saves meaningful current on the LED driver.
// Normal: 150 (~60% duty) — still bright indoors.  Sleep: 30 — just visible.
#define LCD_BL_NORMAL       150
#define LCD_BL_SLEEP        30

// --- Main-loop idle delay ---------------------------------------------------
// A brief yield at the end of each loop() tick lets the RTOS put the CPU
// into its automatic idle sleep between iterations.  10 ms still gives LVGL
// 100 calls/s — well above the 50 ms move-timer cadence.
#define LOOP_IDLE_MS        10

// --- Game tick & telemetry ---------------------------------------------------
#define GAME_TICK_MS               1000UL   // 1 second per game tick
#define TELEMETRY_PUSH_INTERVAL_MS 60000UL  // Push every 60 s (overridden by config.json)
#define TELEMETRY_SAMPLE_INTERVAL_MS 10000UL // Sample metrics every 10 s (overridden by sample_interval_s)
#define METRIC_BATCH_CAP           12       // 12 × ~116 bytes ≈ 1.4 KB RAM
#define WIFI_WAKE_TIMEOUT_MS       15000UL  // Give up waking if no connect in 15 s

// --- Shake detection thresholds (g-force) ------------------------------------
#define SHAKE_GENTLE_G      1.5f  // Gentle shake → play
#define SHAKE_HARD_G        3.0f  // Hard shake → dizzy
#define SHAKE_GENTLE_MS     100   // Must sustain for 100 ms
#define SHAKE_HARD_MS       150   // Must sustain for 150 ms

// --- Demo-speed evolution thresholds (seconds) --------------------------------
// Multiply by 60 for real-world minutes (e.g. 30s demo = 30min real)
#define EVO_EGG_TO_BABY_S   30
#define EVO_BABY_TO_CHILD_S 120
#define EVO_CHILD_TO_TEEN_S 600
#define EVO_TEEN_TO_ADULT_S 1800
#define EVO_ADULT_TO_SENIOR_S 5400
#define EVO_SENIOR_LIFE_S   10800

// --- P1 incident tuning ------------------------------------------------------
#define P1_SPAWN_INTERVAL_S     60    // seconds of age between P1 spawns
#define P1_HEALTH_DRAIN         1     // health lost per game tick while P1 is active
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

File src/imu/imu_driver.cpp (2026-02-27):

#include "imu_driver.h"
#include "../config.h"
#include <Arduino.h>
#include <Wire.h>
#include <FastIMU.h>   // umbrella header — includes F_QMI8658.hpp

// =============================================================================
// State
// =============================================================================
static QMI8658   _imu;
static bool      _ready        = false;
static float     _accel_mag    = 1.0f;   // last measured magnitude (g)
static ShakeLevel _pending     = ShakeLevel::NONE;

// Shake sustain tracking
static float    _shake_peak_g  = 0.0f;
static uint32_t _shake_start_ms = 0;
static bool     _in_shake      = false;

// =============================================================================
// Init
// =============================================================================
void imu_driver_init() {
    Wire.begin(PIN_I2C_SDA, PIN_I2C_SCL, I2C_FREQ);

    calData calib = {};   // no calibration offsets
    int err = _imu.init(calib, IMU_I2C_ADDR);
    if (err != 0) {
        Serial.printf("[imu] QMI8658 init FAILED (err=%d)\n", err);
        _ready = false;
        return;
    }
    _ready = true;
    Serial.println("[imu] QMI8658 ready");
}

// =============================================================================
// Update  (call ~10 Hz)
// =============================================================================
void imu_driver_update() {
    if (!_ready) return;

    AccelData a;
    _imu.update();
    _imu.getAccel(&a);

    float mag = sqrtf(a.accelX * a.accelX +
                      a.accelY * a.accelY +
                      a.accelZ * a.accelZ);
    _accel_mag = mag;

    uint32_t now = millis();

    if (mag >= SHAKE_HARD_G) {
        // Hard shake zone
        if (!_in_shake) {
            _in_shake      = true;
            _shake_start_ms = now;
            _shake_peak_g  = mag;
        } else {
            if (mag > _shake_peak_g) _shake_peak_g = mag;
            if ((now - _shake_start_ms) >= SHAKE_HARD_MS &&
                _pending == ShakeLevel::NONE) {
                _pending = ShakeLevel::HARD;
            }
        }
    } else if (mag >= SHAKE_GENTLE_G) {
        // Gentle shake zone
        if (!_in_shake) {
            _in_shake      = true;
            _shake_start_ms = now;
            _shake_peak_g  = mag;
        } else {
            if (mag > _shake_peak_g) _shake_peak_g = mag;
            if ((now - _shake_start_ms) >= SHAKE_GENTLE_MS &&
                _pending == ShakeLevel::NONE) {
                _pending = ShakeLevel::GENTLE;
            }
        }
    } else {
        // Below threshold — reset detector
        _in_shake     = false;
        _shake_peak_g = 0.0f;
    }
}

// =============================================================================
// Accessors
// =============================================================================
ShakeLevel imu_get_shake() {
    ShakeLevel s = _pending;
    _pending = ShakeLevel::NONE;
    return s;
}

float imu_get_accel_mag() {
    return _accel_mag;
}

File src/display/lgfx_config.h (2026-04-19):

#pragma once
#include <LovyanGFX.hpp>
#include "../config.h"

// =============================================================================
// LGFX — LovyanGFX configuration for Waveshare ESP32-S3-Touch-LCD-1.69
//
// Display: ST7789V2, 240×280 pixels (controller VRAM is 240×320)
// SPI: SPI2_HOST at 80 MHz
// Panel visible window: offset_y=20 (rows 20-299 of the 320-row VRAM)
// =============================================================================

class LGFX : public lgfx::LGFX_Device {
    lgfx::Panel_ST7789 _panel;
    lgfx::Bus_SPI      _bus;
    lgfx::Light_PWM    _bl;

public:
    LGFX() {
        // ---- SPI bus --------------------------------------------------------
        {
            auto cfg = _bus.config();
            cfg.spi_host     = SPI2_HOST;        // ESP32-S3: use SPI2_HOST (not VSPI_HOST)
            cfg.spi_mode     = 0;
            cfg.freq_write   = 40000000UL;       // 40 MHz — safer initial value
            cfg.freq_read    = 6000000UL;
            cfg.spi_3wire    = false;            // use 4-wire; pin_miso=-1 disables MISO
            cfg.use_lock     = true;
            cfg.dma_channel  = SPI_DMA_CH_AUTO;
            cfg.pin_sclk     = PIN_LCD_SCLK;
            cfg.pin_mosi     = PIN_LCD_MOSI;
            cfg.pin_miso     = -1;
            cfg.pin_dc       = PIN_LCD_DC;
            _bus.config(cfg);
            _panel.setBus(&_bus);
        }

        // ---- Panel ----------------------------------------------------------
        {
            auto cfg = _panel.config();
            cfg.pin_cs       = PIN_LCD_CS;
            cfg.pin_rst      = PIN_LCD_RST;
            cfg.pin_busy     = -1;

            // Physical panel is 240×280 but ST7789V2 VRAM is 240×320.
            // The visible 280 rows start at VRAM row 20.
            cfg.panel_width  = LCD_WIDTH;   // 240
            cfg.panel_height = LCD_HEIGHT;  // 280
            cfg.memory_width = 240;
            cfg.memory_height= 320;
            cfg.offset_x     = 0;
            cfg.offset_y     = 20;          // VRAM offset for 280-row panel
            cfg.offset_rotation = 0;

            cfg.invert       = true;        // ST7789V2 requires colour inversion
            cfg.rgb_order    = true;        // RGB (panel is RGB order; false would swap R↔B)
            cfg.readable     = false;
            cfg.bus_shared   = false;
            _panel.config(cfg);
        }
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

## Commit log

2026-02-27 Initial commit: Tamagrotchi ESP32-S3 firmware
    ESP32-S3 (Waveshare 1.69" touch LCD) Tamagotchi featuring Grot,
    the Grafana mascot. Core features:
    - LVGL v9.3 + LovyanGFX display stack with PSRAM draw buffers
    - Grot life-cycle: egg → baby → child → teen → adult → senior
    - Vitals (hunger, happiness, health) with OTLP metrics to Grafana Cloud
    - Sprite engine with 33 frames across 6 animations (walk, wave, jump, etc.)
    - PNG→LVGL converter script (tools/png_to_lvgl.py)
    - IMU shake detection, RTC, battery ADC, buzzer
    - LittleFS config (credentials via data/config.json — see .example)
    [partitions_16M.csv]
2026-02-27 Add README and fix RGB colour order
    - README.md: documents current state, hardware, features, project
    structure, config, build instructions, and remaining work
    - lgfx_config.h: fix rgb_order false→true; BGR mode was swapping R↔B
    causing Grot (and all UI colours) to render with incorrect hues
    [lgfx_config.h]
2026-03-04 Add STLs for hardware case
    [tamagrotchi-back.stl, tamagrotchi-face.stl, tamagrotchi.3mf]
2026-03-04 Add traces to tamaGROTchi
2026-03-05 Add egg stage animation
2026-03-10 Add isntructions for building. update readme
    [button.stl]
2026-03-31 switch to qemu for builds
2026-03-31 chore(deps): pin dependencies
2026-04-01 Add WiFi sleep/batched telemetry, P1 incident mechanic, and firmware CI
    - WiFi sleeps between pushes; metrics sampled every 10s and batch-pushed
    every 60s, cutting average current draw from ~60mA to ~10-15mA
    - Event-driven WiFi state via WiFi.onEvent() — eliminates blocking
    WiFi.status() calls from Core 1, fixing button responsiveness
    - P1 incident mechanic: fires periodically, drains health each tick,
    CLEAN icon flashes red; resolving awards +10 health
    - Pet name (Grafana-themed game_id) shown in status overlay
    - Mini-game metric catcher stub
    - GitHub Actions workflow to build and artifact firmware on every push
    [config.h, config_manager.cpp, lvgl_port.cpp]
2026-04-17 add screen colour invert option to config files
    [config_manager.cpp, lgfx_config.h, lvgl_port.cpp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]
